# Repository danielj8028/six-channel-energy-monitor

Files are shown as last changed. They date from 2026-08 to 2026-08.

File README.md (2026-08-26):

# Six-Channel Whole-Home Energy Monitor

An end-to-end residential energy-monitoring system built around an ESP32 and a dual-ATM90E32 six-channel metering board. The completed system is installed at the electrical panel, records circuit telemetry continuously, stores time-series data on a Raspberry Pi, and exposes a remotely accessible Grafana dashboard.

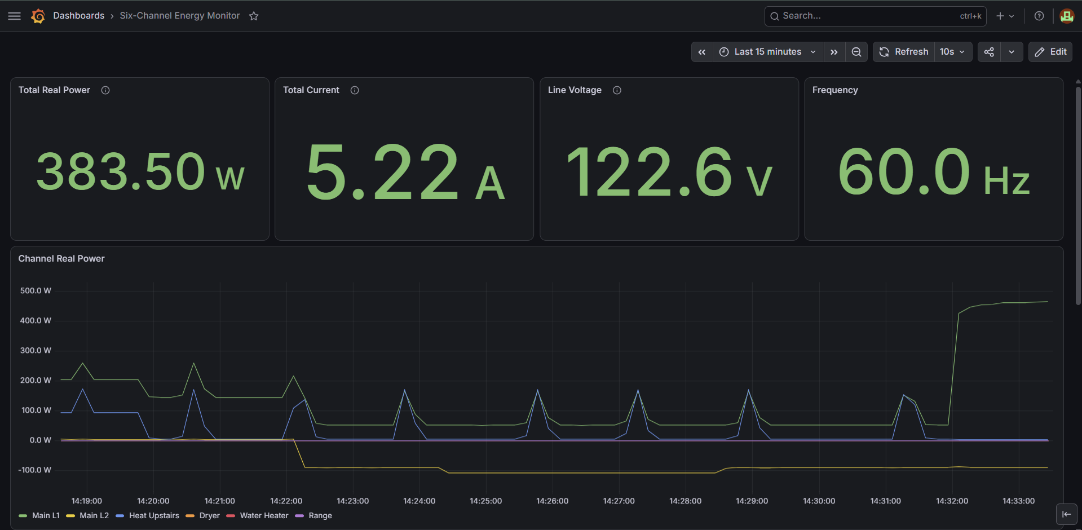
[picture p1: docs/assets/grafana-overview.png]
Live Grafana dashboard showing whole-home power, current, line voltage, frequency, and per-channel history


*Live dashboard view: 383.5 W, 5.22 A, 122.6 V, and 60.0 Hz with per-channel power history.*

## What I built

- Installed two split-core CTs on the incoming 120/240 V service conductors and four CTs on selected branch circuits
- Measured RMS current and voltage, real/reactive/apparent power, power factor, frequency, and energy
- Calibrated voltage and each CT family against handheld reference instruments
- Published ESP32 telemetry over MQTT every 10 seconds
- Hosted MQTT ingestion, InfluxDB, and Grafana continuously on a Raspberry Pi using Docker
- Built a dashboard for per-channel measurements, whole-home power, and historical trends
- Added secure remote dashboard access with Tailscale
- Demonstrated remote ESPHome OTA updates by tunneling through the Raspberry Pi

## System architecture

```mermaid
flowchart TD
    A["2 service CTs + 4 branch CTs"] --> B["Dual ATM90E32 metering board"]
    C["9 VAC voltage reference"] --> B
    B --> D["ESP32 + ESPHome"]
    D -->|MQTT over Wi-Fi| E["Raspberry Pi / Docker"]
    E --> F["InfluxDB time-series storage"]
    F --> G["Grafana dashboards"]
    G --> H["Local or Tailscale access"]
```

See [Architecture](docs/architecture.md) for the data path and design decisions.

## AutoCAD electrical documentation

The installed system is documented with an AutoCAD single-line drawing covering the 120/240 VAC utility service, residential load center, main and branch CT placement, isolated 9 VAC voltage reference, ATM90E32 metering board, ESP32/MQTT link, and Raspberry Pi telemetry backend.

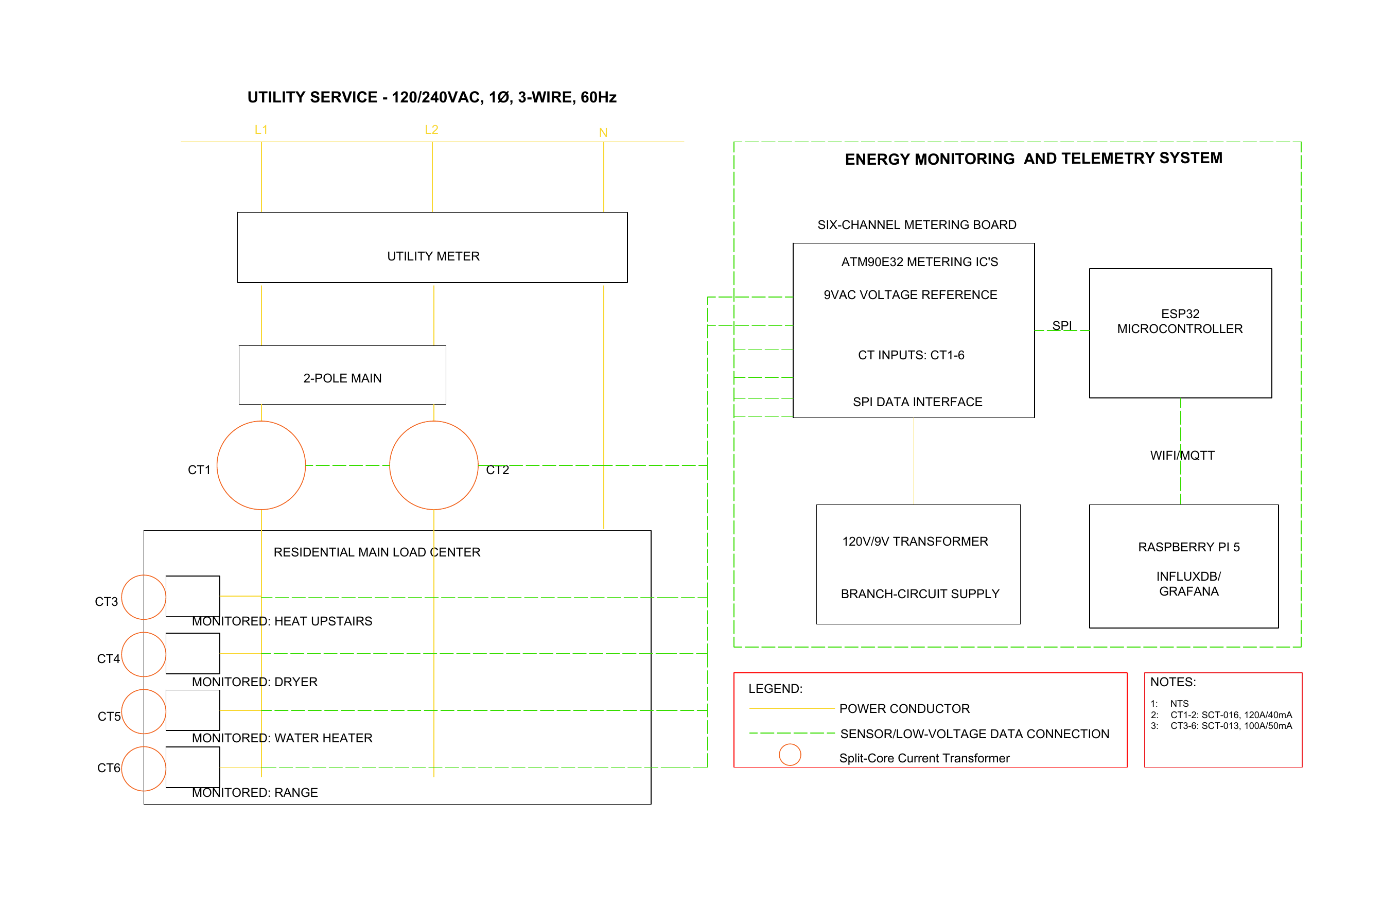
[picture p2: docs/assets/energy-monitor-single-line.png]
AutoCAD single-line diagram for the six-channel energy monitor


View the [full-resolution PDF](docs/cad/energy-monitor-single-line.pdf) or download the editable [AutoCAD DWG source](docs/cad/energy-monitor-single-line.dwg).

## Live telemetry

The dashboard separates the two service legs from the monitored upstairs heat, dryer, water-heater, and range circuits. In addition to current and real power, the lower panels expose power factor, reactive power, and apparent power for load-behavior analysis.

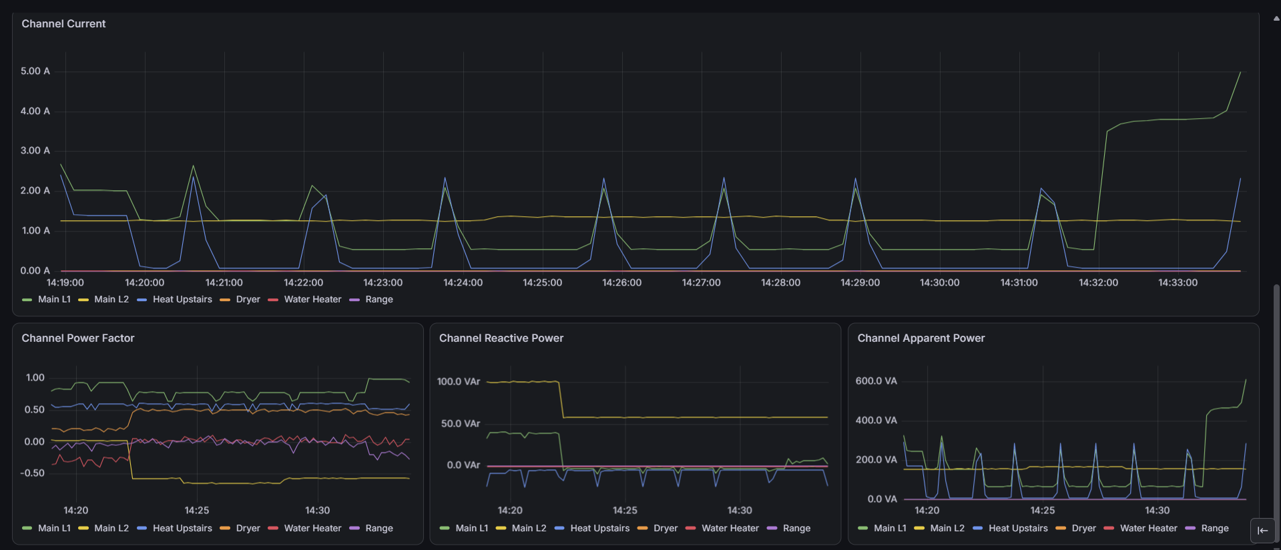
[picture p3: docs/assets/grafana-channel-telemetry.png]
Grafana per-channel current, power factor, reactive power, and apparent power panels


The screenshot captures real household transitions at a 10-second refresh interval, including recurring upstairs-heat demand and a larger Main L1 step near the end of the window.

## Hardware

| Component | Function |
|---|---|
| ESP32 DevKitC | Firmware host, networking, MQTT, and OTA |
| CircuitSetup six-channel board | Two ATM90E32 metering ICs and CT interfaces |
| 2× SCT-016, 120 A/40 mA | Main service conductors (CT1 and CT2) |
| 4× SCT-013-000, 100 A/50 mA | Selected branch circuits (CT3 through CT6) |
| 9 VAC AC-AC adapter | Isolated line-voltage waveform reference |
| Raspberry Pi | Always-on Docker host for the monitoring stack |
| Clamp meter and multimeter | Calibration references |

## Software stack

| Layer | Technology |
|---|---|
| Embedded firmware | ESPHome |
| Metering interface | ATM90E32 over SPI |
| Telemetry transport | MQTT |
| Ingestion | Telegraf |
| Time-series database | InfluxDB |
| Visualization | Grafana |
| Deployment | Docker on Raspberry Pi |
| Remote access | Tailscale |

## Calibration results

### Branch-circuit CTs

The SCT-013-000 gain was calibrated with a tower fan at three steady operating points. The gain changed from `27518` to `28646`.

| Fan setting | Clamp meter | Before calibration | Initial error |
|---|---:|---:|---:|
| Speed 1 | 0.660 A | 0.630 A | -4.5% |
| Speed 2 | 0.740 A | 0.710 A | -4.1% |
| Speed 3 | 0.885 A | 0.855 A | -3.4% |

After calibration, the monitor matched the clamp meter at the displayed 0.01 A resolution across the three test points.

### Main-service CTs

The two SCT-016 sensors were calibrated individually after installation under higher household loads.

| Channel | Monitor before correction | Clamp reference | Final gain |
|---|---:|---:|---:|
| CT1 trial 1 | 18.37 A | 27.49 A | `62250` |
| CT1 trial 2 | 23.40 A | 34.69 A | `62250` |
| CT2 | 4.78 A | 6.76 A | `59095` |

### Voltage

The voltage gain changed from `7305` to `6921`, correcting the monitor from 129.3 V to approximately 122.6–122.7 V against a 122.5 V reference.

The full method and calculations are in [Calibration](docs/calibration.md). Raw tower-fan samples and the processed CSV are retained in [`data/`](data/).

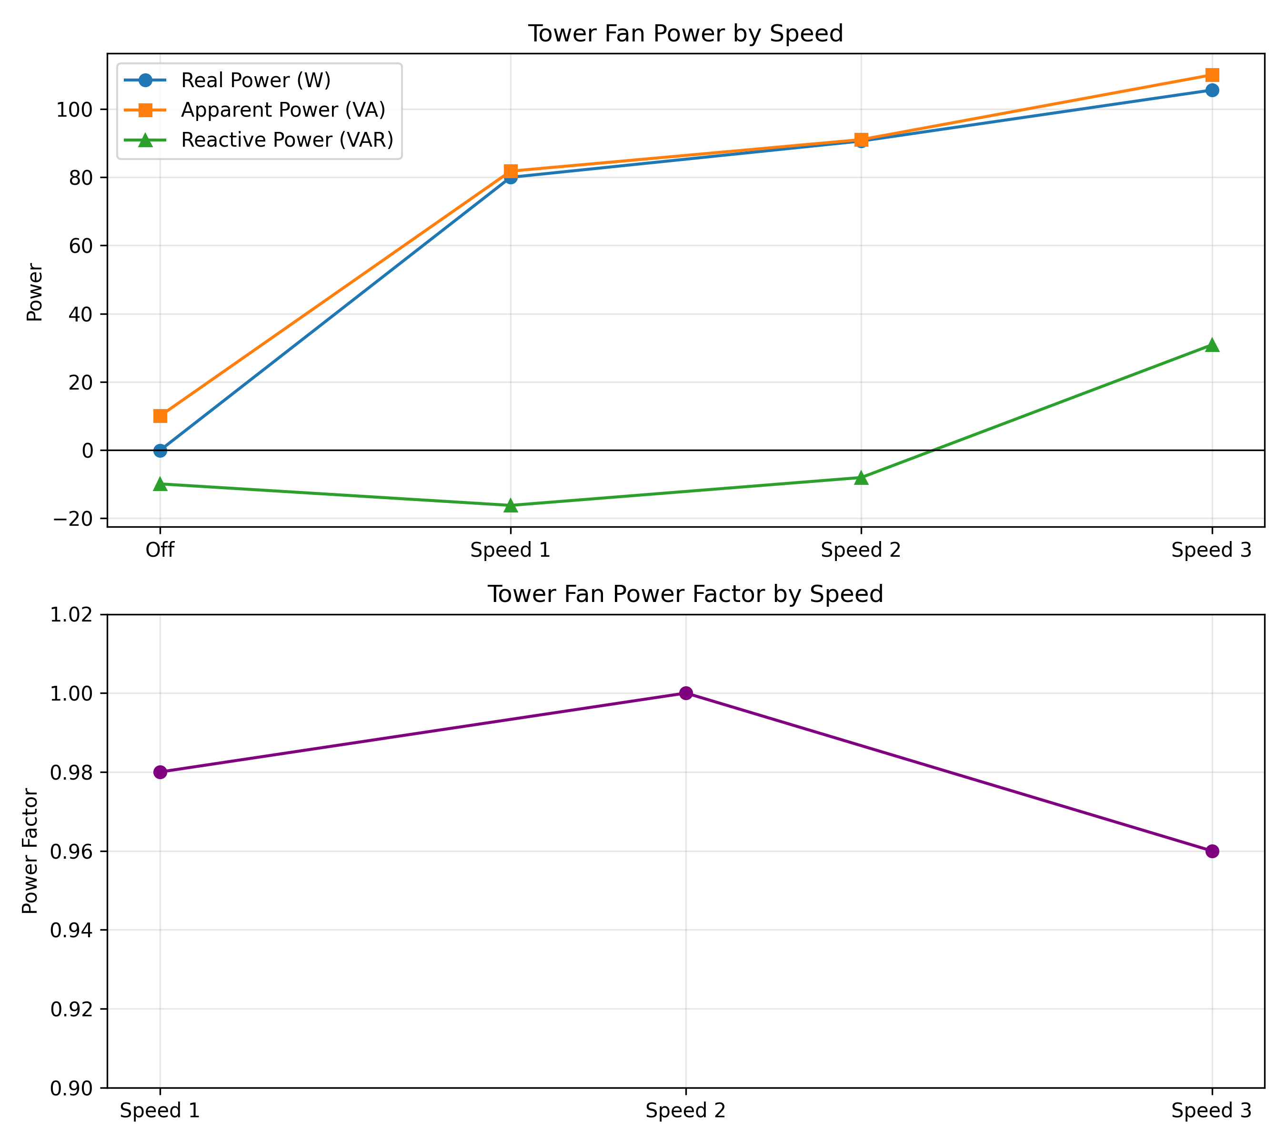
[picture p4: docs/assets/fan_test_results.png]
Tower-fan calibration results across off and three speed settings


## Final system status

As of August 2026, the monitor is:

- physically installed and operating continuously
- reporting all six channels with correct CT polarity
- storing measurements in InfluxDB
- displaying live and historical data in Grafana
- accessible remotely through a private Tailscale network
- remotely updateable through an SSH tunnel to the Raspberry Pi

## Physical commissioning

The photo below documents the exterior commissioning configuration: six CT leads exit the panel and connect to the ESP32/ATM90E32 assembly while the isolated 9 VAC reference is powered from the adjacent receptacle. The exposed-board arrangement shown here was used for commissioning and validation; a covered enclosure and secured cable routing are the appropriate final mechanical configuration.

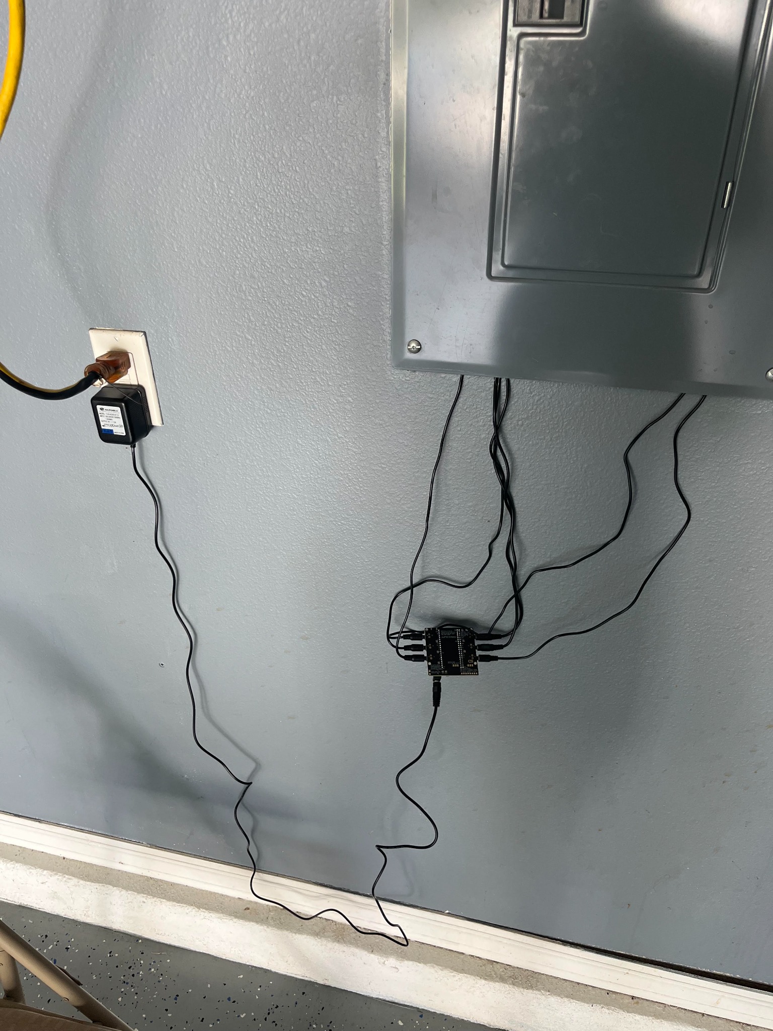
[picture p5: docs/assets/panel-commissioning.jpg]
Electrical panel and externally mounted six-channel metering assembly during commissioning


## Repository contents

| Path | Contents |
|---|---|
| [`energy_meter.yaml`](energy_meter.yaml) | Sanitized active ESPHome configuration |
| [`secrets.example.yaml`](secrets.example.yaml) | Credential template; no real secrets |
| [`docs/architecture.md`](docs/architecture.md) | System and data-flow design |
| [`docs/calibration.md`](docs/calibration.md) | Reference measurements and gain calculations |
| [`docs/installation.md`](docs/installation.md) | Installation design and safety boundaries |
| [`docs/backend.md`](docs/backend.md) | Raspberry Pi, Docker, data, and remote access overview |
| [`docs/cad/`](docs/cad/) | AutoCAD DWG source and plotted PDF single-line diagram |
| [`build-log.md`](build-log.md) | Chronological engineering build log |
| [`data/`](data/) | Bench-test source data and analysis script |

## Reproducing the firmware configuration

1. Install ESPHome.
2. Copy `secrets.example.yaml` to `secrets.yaml`.
3. Replace every placeholder locally. `secrets.yaml` is intentionally ignored by Git.
4. Validate the configuration:

   ```bash
   esphome config energy_meter.yaml
   ```

5. Compile and upload only after adapting the calibration constants, network settings, and channel assignments to the target hardware.

## Safety

This repository documents a personal engineering project; it is not an installation guide for energized electrical equipment. Service conductors can remain energized even when the main breaker is open. Work in or around a panel should be performed only by a qualified person using applicable codes, permits, protective equipment, and manufacturer instructions. Split-core CT secondaries must never be left open while clamped around an energized conductor unless the CT is specifically designed to be safe in that condition.

## Author

Daniel Joseph - Electrical Engineering student, University of Florida

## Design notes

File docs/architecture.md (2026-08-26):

# Architecture

## Electrical single-line drawing

The project includes an AutoCAD drawing that connects the electrical installation to the telemetry architecture. It documents the 120/240 VAC service, CT1 and CT2 on the two main service legs, CT3 through CT6 on selected branch circuits, the isolated voltage-reference transformer, the ATM90E32 metering board, ESP32, MQTT transport, and Raspberry Pi-hosted InfluxDB/Grafana stack.

AutoCAD single-line diagram

- [Full-resolution PDF](cad/energy-monitor-single-line.pdf)
- [Editable AutoCAD DWG](cad/energy-monitor-single-line.dwg)

## Measurement path

Each split-core current transformer produces a scaled waveform proportional to conductor current. A 9 VAC adapter provides an isolated representation of line voltage. Two ATM90E32 metering ICs sample these signals and calculate RMS current, RMS voltage, real power, reactive power, apparent power, power factor, and frequency.

The ESP32 communicates with both metering ICs over SPI. ESPHome exposes local diagnostics and publishes measurements to MQTT at a 10-second interval.

## Data path

```mermaid
sequenceDiagram
    participant CT as CTs and voltage reference
    participant Meter as ATM90E32 pair
    participant ESP as ESP32
    participant Pi as Raspberry Pi
    participant DB as InfluxDB
    participant UI as Grafana
    CT->>Meter: Analog waveforms
    Meter->>ESP: SPI measurements
    ESP->>Pi: MQTT telemetry
    Pi->>DB: Telegraf writes
    DB->>UI: Time-series queries
```

## Channel model

| Channel | Sensor | Role | Metering IC |
|---|---|---|---|
| CT1 | SCT-016 120 A/40 mA | Main service L1 | IC1, phase A |
| CT2 | SCT-016 120 A/40 mA | Main service L2 | IC1, phase B |
| CT3 | SCT-013-000 100 A/50 mA | Selected branch circuit | IC1, phase C |
| CT4 | SCT-013-000 100 A/50 mA | Selected branch circuit | IC2, phase A |
| CT5 | SCT-013-000 100 A/50 mA | Selected branch circuit | IC2, phase B |
| CT6 | SCT-013-000 100 A/50 mA | Selected branch circuit | IC2, phase C |

CT1 and CT2 use independent calibration gains because the two main-service sensors were calibrated separately. CT3 through CT6 share the calibrated SCT-013-000 gain.

## Design decisions

- **Local-first operation:** measurement and storage continue on the home LAN if internet access is unavailable.
- **Time-series storage:** InfluxDB retains high-resolution historical measurements rather than only showing instantaneous values.
- **Containerized backend:** Docker keeps the Raspberry Pi services reproducible and isolated.
- **Private remote access:** Tailscale exposes the dashboard only to authenticated devices on the private tailnet; Grafana is not opened directly to the public internet.
- **Remote maintenance:** an SSH tunnel through the Raspberry Pi can forward the ESPHome OTA port to a remote development computer.

## Measurement caveats

- `Total Amps` is the arithmetic sum of all six channel magnitudes. Because the branch channels are subsets of the main channels, it is a diagnostic aggregate, not whole-home line current.
- `Total Watts` likewise double-counts loads when main and branch channels are summed together. Whole-home demand should be calculated from CT1 and CT2 only; branch channels should be graphed separately.
- Power factor and reactive power become unstable near the noise floor. Dashboard queries should suppress or annotate low-current measurements.

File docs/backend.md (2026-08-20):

# Backend and Remote Access

## Always-on host

A Raspberry Pi named `energy-monitor-pi` runs the monitoring services continuously in Docker. The core services are:

- MQTT broker for ESP32 telemetry
- Telegraf for ingestion and field mapping
- InfluxDB for time-series retention
- Grafana for dashboards and historical queries

The ESP32 publishes a new measurement set every 10 seconds. The system continues collecting data on the local network during an internet outage, provided the ESP32, Wi-Fi router, and Raspberry Pi remain powered.

## Dashboard

Grafana panels display line voltage, frequency, CT current, real power, reactive power, apparent power, power factor, total energy, and time trends. Low-current power-factor and reactive-power values should be interpreted cautiously because noise is significant relative to the measured signal.

Grafana overview with live electrical measurements and per-channel real-power trends

Grafana channel-current, power-factor, reactive-power, and apparent-power panels

These views also serve as the visible query layer over the measurements retained in InfluxDB: Grafana reads the historical series and renders synchronized per-channel trends over the selected time window.

## Remote access

Tailscale provides encrypted private-network access to the Raspberry Pi and Grafana without publishing Grafana directly to the internet. Authorized devices can reach the dashboard using the Pi hostname while Tailscale is connected.

## Remote OTA workflow

The final main-CT calibration was deployed remotely. The development computer created an SSH tunnel to `energy-monitor-pi`, forwarding the ESPHome OTA port from the home-network ESP32. ESPHome then uploaded firmware through the local end of that tunnel.

Only the OTA port was forwarded during that operation. Consequently, firmware upload succeeded even though ESPHome's subsequent attempt to attach to API logs on port 6053 was refused. The `OTA successful` and `Successfully uploaded program` messages confirmed deployment.

## Security practices

- Wi-Fi and MQTT credentials live only in the ignored `secrets.yaml` file.
- `secrets.example.yaml` documents the required keys without real values.
- The public configuration does not contain the MQTT broker's private address.
- Grafana is reached through the private Tailscale network rather than public port forwarding.
- Repository scans should be performed before every public push.

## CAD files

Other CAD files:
docs/cad/energy-monitor-single-line.dwg

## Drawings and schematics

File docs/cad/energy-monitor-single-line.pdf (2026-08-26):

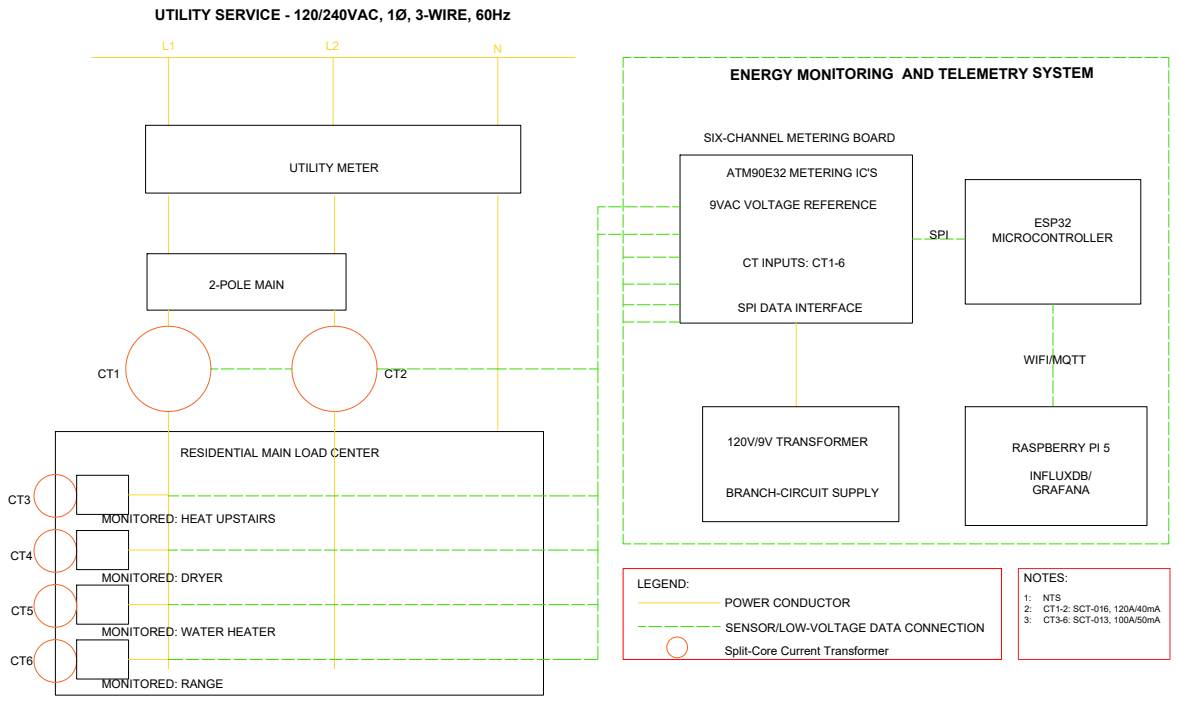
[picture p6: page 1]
UTILITY SERVICE - 120/240VAC, 1Ø, 3-WIRE, 60Hz L1; N UTILITY METER 2-POLE MAIN CT1; CT2 RESIDENTIAL MAIN LOAD CENTER CT3 CT4 CT5 CT6; MONITORED: HEAT UPSTAIRS MONITORED: DRYER MONITORED: WATER HEATER MONITORED: RANGE; ENERGY MONITORING AND TELEMETRY SYSTEM SIX-CHANNEL METERING BOARD ATM90E32 METERING IC'S 9VAC VOLTAGE REFERENCE CT INPUTS: CT1-6 SPI DATA INTERFACE; ESP32 SPI; MICROCONTROLLER WIFI/MQTT RASPBERRY PI 5 INFLUXDB/ GRAFANA 120V/9V TRANSFORMER BRANCH-CIRCUIT SUPPLY LEGEND: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

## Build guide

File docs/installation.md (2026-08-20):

# Installation

## Installed configuration

The completed system uses two SCT-016 split-core sensors for the two incoming service conductors and four SCT-013-000 sensors for selected branch circuits. CT polarity was verified from the sign of real power. The ESP32 and metering board remain outside the panel, while CT leads route through the panel boundary to the measurement assembly.

Exterior panel and six-channel metering assembly during commissioning

The photograph shows the commissioning configuration used to validate all six installed CTs. The board is intentionally identified as exposed commissioning hardware rather than presented as a finished enclosure; long-term deployment should use a covered enclosure, strain relief, and secured cable routing appropriate to the environment.

The 9 VAC adapter serves two functions: it powers the measurement assembly and provides the isolated voltage waveform used for phase-sensitive power calculations. If it is disconnected, a CT may still indicate current while voltage, frequency, and real-power calculations become unavailable or invalid.

## Commissioning checks

1. Confirm each split-core CT is fully latched around exactly one insulated conductor.
2. Confirm every CT lead is connected before the monitored conductor is energized, following the CT manufacturer's requirements.
3. Verify approximately 120–123 V and 60 Hz from the voltage-reference channel.
4. Switch known loads on and off and confirm the expected channel responds.
5. Reverse a CT only if a known consuming load produces consistently negative real power.
6. Compare installed main-channel current with a reference clamp meter under stable load.
7. Confirm MQTT ingestion, database writes, and Grafana timestamps before leaving the system unattended.

## Safety boundary

This page records the completed project's commissioning logic; it is not a procedure for working in an energized panel. Opening a main breaker does not de-energize the utility-side service conductors or lugs. Electrical-panel work should be performed only by a qualified person using applicable codes, permits, PPE, test equipment, and manufacturer instructions.

CTs with current-output secondaries can develop hazardous voltage if their secondary is opened while installed on an energized conductor. Sensor datasheets and the metering-board documentation govern the permitted connection sequence.

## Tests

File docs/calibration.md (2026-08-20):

# Calibration

## Gain calculation

Current gain was corrected with simultaneous reference measurements:

\[
G_{new}=G_{old}\left(\frac{I_{reference}}{I_{monitor}}\right)
\]

Multiple stable readings were used where possible rather than calibrating from a single low-current point.

## SCT-013-000 branch sensors

The initial gain was `27518`. A tower fan provided three repeatable load levels.

| Setting | Clamp meter | Monitor | Ratio |
|---|---:|---:|---:|
| Speed 1 | 0.660 A | 0.630 A | 1.0476 |
| Speed 2 | 0.740 A | 0.710 A | 1.0423 |
| Speed 3 | 0.885 A | 0.855 A | 1.0351 |

The deployed branch-sensor gain is `28646`. All six inputs were separately checked by moving the same CT and load between channels before permanent installation.

## SCT-016 main sensors

The main sensors were calibrated after installation so the test current was large enough to reduce the relative influence of noise and quantization.

### CT1

| Trial | Monitor | Clamp meter | Correction ratio |
|---|---:|---:|---:|
| 1 | 18.37 A | 27.49 A | 1.4965 |
| 2 | 23.40 A | 34.69 A | 1.4825 |

The two independently calculated gains were approximately 62,521 and 61,958. Their average is approximately 62,240; the deployed value is `62250`.

### CT2

| Monitor | Clamp meter | Correction ratio | Deployed gain |
|---:|---:|---:|---:|
| 4.78 A | 6.76 A | 1.4142 | `59095` |

## Voltage

| Measurement | Value |
|---|---:|
| Reference meter | 122.5 V |
| Monitor before calibration | 129.3 V |
| Initial gain | `7305` |
| Final gain | `6921` |
| Monitor after calibration | 122.6–122.7 V |

## Polarity verification

A positive-consuming load should report positive real power. Negative real power during early bench tests was corrected by reversing CT orientation. Very small negative readings near zero load can still occur because phase error and noise dominate at low current.

## Bench dataset

The `data/` directory contains the raw 10-second samples, processed summary, and plotting script used for the tower-fan experiment. The source dataset is retained so the plotted results can be audited and regenerated.

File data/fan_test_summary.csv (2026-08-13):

condition | current_A | real_power_W | power_factor | reactive_power_VAR | apparent_power_VA
fan_off | 0.08 | -0.07 |  | -9.90 | 10.02
speed_1 | 0.67 | 80.00 | 0.98 | -16.20 | 81.80
speed_2 | 0.74 | 90.63 | 1.00 | -8.03 | 91.05
speed_3 | 0.90 | 105.58 | 0.96 | 30.87 | 110.03

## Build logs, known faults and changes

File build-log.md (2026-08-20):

# Smart Home Energy Monitor Build Log

## Bench Validation — CT1/CT2/CT3

Date: 2026-08-02

Setup:

- ESP32 mounted to CircuitSetup 6-channel energy meter board

- ESPHome firmware flashed and web dashboard accessible

- 9VAC AC-AC adapter used as voltage reference

- SCT-013-000 current transformer used for bench testing

- Lamp cord separated into individual insulated conductors

- CT clamped around one insulated conductor only

Results:

- CT1 showed approximately 0.11 A and 8.8 W with lamp ON

- CT1 dropped to approximately 0 A / 0 W with lamp OFF

- CT2 showed similar readings when the same CT was moved to CT2

- CT3 showed similar readings when the same CT was moved to CT3

- Frequency reading held at 60.0 Hz

- Initial negative watt reading was corrected by flipping CT orientation

Conclusion:

- ESP32, CircuitSetup board, ATM90E32 IC1, voltage reference, and CT channels 1–3 are functional.

- Bench test confirms current and real power readings respond correctly to load on/off state.

Next Steps:

- Validate CT4, CT5, and CT6

- Test a larger load for clearer current/power readings

- Begin calibration using a known load or clamp meter

____________________________________________________________________

## Full 6-Channel Bench Validation

Date: 2026-08-02

Test:

- Moved the same SCT-013-000 CT across all six CT inputs.

- Used the same lamp load and split single-conductor cord setup for each channel.

- Took screenshots for lamp ON and lamp OFF states on CT1 through CT6.

Results:

- CT1, CT2, CT3, CT4, CT5, and CT6 all responded to lamp ON/OFF state.

- Lamp ON produced nonzero current and watt readings.

- Lamp OFF dropped readings near zero.

- CT orientation was corrected so watts were positive.

Conclusion:

- All six CT input channels are functional.

- Both ATM90E32 metering ICs are communicating with the ESP32.

- The CircuitSetup board, ESPHome firmware, voltage reference, and CT sensing path are bench validated.

____________________________________________________________________

## Larger Load Test — Tower Fan

Date: 2026-08-02

Setup:

- Tower fan plugged into a split extension cord test setup

- SCT-013-000 CT connected to CT1

- CT clamped around one separated insulated conductor

- 9VAC adapter used as voltage reference

- ESPHome web dashboard used to monitor readings

Results:

- Tower fan ON: CT1 measured approximately 0.88 A and 108.8 W

- Tower fan OFF: CT1 dropped near 0 A / 0 W

- Frequency remained at 60.0 Hz

Conclusion:

- The energy monitor responds correctly to a larger real-world appliance load.

- Current and wattage readings scale upward compared with the small lamp test.

---

## Instrument Calibration

**Date:** 2026-08-13

- Calibrated the 9 VAC voltage reference from gain `7305` to `6921` using a handheld reference measurement.
- Calibrated the SCT-013-000 branch CT gain from `27518` to `28646` using three tower-fan operating points.
- Logged 10-second current and power samples and retained the raw dataset, processed CSV, plot, and analysis script.
- Verified the calibrated voltage at approximately 122.6–122.7 V against a 122.5 V reference.

## Raspberry Pi Monitoring Stack

**Date:** 2026-08-13 to 2026-08-17

- Deployed the MQTT, Telegraf, InfluxDB, and Grafana data path on an always-on Raspberry Pi using Docker.
- Built dashboards for per-channel current, real/reactive/apparent power, power factor, voltage, frequency, and total energy.
- Configured Tailscale and verified dashboard access from a phone with home Wi-Fi disabled.
- Reserved a stable LAN address and verified hostname-based access to `energy-monitor-pi`.

## Panel Installation and Commissioning

**Date:** 2026-08-20

- Installed two SCT-016 sensors on the incoming service conductors and four SCT-013-000 sensors on selected branch circuits.
- Verified correct CT polarity from real-power direction and confirmed live data for all six channels.
- Observed stable household measurements near 122 V and 60 Hz in Grafana.
- Calibrated CT1 from two simultaneous monitor/clamp-meter comparisons, producing a final gain of `62250`.
- Calibrated CT2 from a simultaneous 4.78 A monitor and 6.76 A clamp-meter comparison, producing a final gain of `59095`.

## Remote OTA Deployment

**Date:** 2026-08-20

- Connected from Gainesville to the home Raspberry Pi over Tailscale.
- Forwarded the ESPHome OTA port through an SSH tunnel from the Pi to the ESP32.
- Compiled and uploaded the final per-main calibration values remotely.
- Confirmed successful OTA deployment and verified updated live readings in Grafana.

## Final Status

The six-channel whole-home monitor is installed, calibrated, logging continuously, remotely viewable, and remotely updateable. Remaining work is optional long-term refinement such as dashboard thresholding near the measurement noise floor and periodic reference verification.

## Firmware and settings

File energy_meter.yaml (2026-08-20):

substitutions:
  disp_name: energy_meter
  update_time: 10s
  current_cal_ct1: '62250'      # SCT-016 main L1
  current_cal_ct2: '59095'      # SCT-016 main L2
  current_cal_branch: '28646'   # SCT-013-000 branch circuits
  voltage_cal: '6921'           # 9 VAC voltage reference

esphome:
  name: energy-meter

esp32:
  variant: esp32

wifi:
  ssid: !secret wifi_ssid
  password: !secret wifi_password

logger:

api:
  reboot_timeout: 0s

mqtt:
  broker: !secret mqtt_broker
  username: !secret mqtt_username
  password: !secret mqtt_password
  topic_prefix: energy-meter

ota:
  - platform: esphome

web_server:
  port: 80

spi:
  clk_pin: 18
  miso_pin: 19
  mosi_pin: 23

sensor:
  - platform: wifi_signal
    name: ${disp_name} WiFi
    update_interval: 60s

  # ATM90E32 IC1: CT1, CT2, CT3
  - platform: atm90e32
    cs_pin: 5
    phase_a:
      voltage:
        name: ${disp_name} Volts A
        id: ic1Volts
        accuracy_decimals: 1
      current:
        name: ${disp_name} CT1 Amps
        id: ct1Amps
      power:
        name: ${disp_name} CT1 Watts
        id: ct1Watts
      power_factor:
        name: ${disp_name} CT1 Power Factor
        id: ct1PowerFactor
        accuracy_decimals: 2
      reactive_power:
        name: ${disp_name} CT1 Reactive Power
        id: ct1ReactivePower
        accuracy_decimals: 1
      apparent_power:
        name: ${disp_name} CT1 Apparent Power
        id: ct1ApparentPower
        accuracy_decimals: 1
      gain_voltage: ${voltage_cal}
      gain_ct: ${current_cal_ct1}

    phase_b:
      current:
        name: ${disp_name} CT2 Amps
        id: ct2Amps
      power:
        name: ${disp_name} CT2 Watts
        id: ct2Watts
      power_factor:
        name: ${disp_name} CT2 Power Factor
        id: ct2PowerFactor
        accuracy_decimals: 2
      reactive_power:
        name: ${disp_name} CT2 Reactive Power
        id: ct2ReactivePower
        accuracy_decimals: 1
      apparent_power:
        name: ${disp_name} CT2 Apparent Power
        id: ct2ApparentPower
        accuracy_decimals: 1
      gain_voltage: ${voltage_cal}
      gain_ct: ${current_cal_ct2}

    phase_c:
      current:
        name: ${disp_name} CT3 Amps
        id: ct3Amps
      power:
        name: ${disp_name} CT3 Watts
        id: ct3Watts
      power_factor:
        name: ${disp_name} CT3 Power Factor
        id: ct3PowerFactor
        accuracy_decimals: 2
      reactive_power:
        name: ${disp_name} CT3 Reactive Power
        id: ct3ReactivePower
        accuracy_decimals: 1
      apparent_power:
        name: ${disp_name} CT3 Apparent Power
        id: ct3ApparentPower
        accuracy_decimals: 1
      gain_voltage: ${voltage_cal}
      gain_ct: ${current_cal_branch}

    frequency:
      name: ${disp_name} Freq A
    line_frequency: 60Hz
    gain_pga: 1X
    update_interval: ${update_time}

  # ATM90E32 IC2: CT4, CT5, CT6
  - platform: atm90e32
    cs_pin: 4
    phase_a:
      current:
        name: ${disp_name} CT4 Amps
        id: ct4Amps
      power:
        name: ${disp_name} CT4 Watts
        id: ct4Watts
      power_factor:
        name: ${disp_name} CT4 Power Factor
        id: ct4PowerFactor
        accuracy_decimals: 2
      reactive_power:
        name: ${disp_name} CT4 Reactive Power
        id: ct4ReactivePower
        accuracy_decimals: 1
      apparent_power:
        name: ${disp_name} CT4 Apparent Power
        id: ct4ApparentPower
        accuracy_decimals: 1
      gain_voltage: ${voltage_cal}
      gain_ct: ${current_cal_branch}

    phase_b:
      current:
        name: ${disp_name} CT5 Amps
        id: ct5Amps
      power:
        name: ${disp_name} CT5 Watts
        id: ct5Watts
      power_factor:
        name: ${disp_name} CT5 Power Factor
        id: ct5PowerFactor
        accuracy_decimals: 2
      reactive_power:
        name: ${disp_name} CT5 Reactive Power
        id: ct5ReactivePower
        accuracy_decimals: 1
      apparent_power:
        name: ${disp_name} CT5 Apparent Power
        id: ct5ApparentPower
        accuracy_decimals: 1
      gain_voltage: ${voltage_cal}
      gain_ct: ${current_cal_branch}

    phase_c:
      current:
        name: ${disp_name} CT6 Amps
        id: ct6Amps
      power:
        name: ${disp_name} CT6 Watts
        id: ct6Watts
      power_factor:
        name: ${disp_name} CT6 Power Factor
        id: ct6PowerFactor
        accuracy_decimals: 2
      reactive_power:
        name: ${disp_name} CT6 Reactive Power
        id: ct6ReactivePower
        accuracy_decimals: 1
      apparent_power:
        name: ${disp_name} CT6 Apparent Power
        id: ct6ApparentPower
        accuracy_decimals: 1
      gain_voltage: ${voltage_cal}
      gain_ct: ${current_cal_branch}

    frequency:
      name: ${disp_name} Freq B
    line_frequency: 60Hz
    gain_pga: 1X
    update_interval: ${update_time}
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

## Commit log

2026-08-13 Complete calibrated six-channel energy monitor bench validation
    [energy_meter_calibrated_backup.yaml, fan_test_summary.csv]
2026-08-20 Document final installation, calibration, and monitoring stack
    [energy_meter_calibrated_backup.yaml, fan_test_summary.csv]
2026-08-26 Add AutoCAD electrical single-line documentation
    [energy-monitor-single-line.dwg]
